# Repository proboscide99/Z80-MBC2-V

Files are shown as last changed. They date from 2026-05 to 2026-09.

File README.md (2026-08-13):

# Z80-MBC2-V

The **Z80-MBC2-V** is a variant of the popular Z80-MBC2 (Multi Boot Computer) by Just4Fun.

## Main Features
- WizNet W5500 ethernet port with TELNET capability (remote terminal - CP/M 3.0 physical device - CBBS)
- 512KB Supercap-backed RAM (some of which can be (has been) used for a CP/M 3.0 352KB RamDisk)
- RC2014 bus and Test points for I/O expansion / logic analysis
- Optional 8-24V power supply
- USB-C port for power and serial communication
- TTL serial I/O (as an alternative to USB)
- 3,3V I2C interface for a small (128x64) auxiliary onboard OLED display
- Z80 CMOS running up to 10MHz
- ATMega1284P for I/O
- RTC
- Hardware watchdog for ATmega and IOS-based software watchdog for Z80
- Fully software compatible with original project

## 🌐 Project Page
[https://www.probosci.de/Z80mbc](https://www.probosci.de/Z80mbc)

---

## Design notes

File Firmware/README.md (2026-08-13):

## AVR 1284P MCU Programming

This project has been tested using **Arduino IDE 1.8.19** with **MightyCore v2.2.2**, so the verified instructions provided below are related to this environment.

You can, of course, compile it from source and program it into the MCU using Arduino IDE 2.x and a more recent version of MightyCore.  

If you use a different tool version, please leave a message so the instructions for that specific setup can be added.

If your device is blank, you first need to program it using an external hardware programmer (you cannot upload the sketch directly via the serial port).

The repository provides both source code and pre-compiled .hex files (with and without a bootloader).  
The bootloader embedded in the file is **Optiboot**, configured for a **20MHz** crystal.

---

## Why MightyCore 2.2.2?

* Older versions lack functionalities required for this project (such as the ability to configure the serial buffer size)  
* Newer versions (starting from v3.x) replaced the Optiboot bootloader with Urboot, which is not compatible with IDE 1.8.19  

> [!NOTE]
> MightyCore v2.2.2 can be easily found online. A copy of the archive is also included in this repository.

Two files from the original 2.2.2 MightyCore need to be modified: `avrdude.conf` (mandatory) and `boards.txt` (recommended).

### 1. avrdude.conf
Even though MightyCore 2.2.2 is the correct core to use for IDE 1.8.19, its bundled `avrdude.conf` file was already prepared for the transition to AVRDUDE 7.x.  
It contains directives—such as `default_spi = "";`—that the AVRDUDE 6.3 interpreter cannot understand.

Replace this file with the native one from your Arduino IDE installation:
* **Source File**: `arduino-1.8.19/hardware/tools/avr/etc/avrdude.conf`
* **Destination Path**: `hardware/MightyCore/avr/avrdude.conf`

After this change, MightyCore 2.2.2 will work flawlessly with Arduino v1.8.19.

### 2. boards.txt
A modified `boards.txt` file is included in this repository with two simple, minor changes in the `1284/P` section.
If you have already customized your `boards.txt` file, do not replace it; just modify these two lines instead:

In the `1284/P` section:

* **Change the lock bits value** from `0xcf` to `0x0f` (using the older `0xCF` value would cause a non-fatal validation error):
  ```text
  #1284.bootloader.lock_bits=0xcf
  1284.bootloader.lock_bits=0x0f
  ```

* **Locate the row** `1284.menu.LTO.Os.compiler.cpp.extra_flags=` and add `-DSERIAL_RX_BUFFER_SIZE=1024`, so the line looks like:
  ```text
  1284.menu.LTO.Os.compiler.cpp.extra_flags=-DSERIAL_RX_BUFFER_SIZE=1024
  ```

This configures a larger (1KB) serial buffer size, allowing the Z80-MBC2 IOS firmware to better handle data transfers over the serial port.
IOS will recognize this flag and display the buffer size in the boot menu.

---

## Programming the MCU

For testing purposes, you may do this with a minimal hardware configuration (i.e., without the Z80, RAM, SD-CARD, Ethernet, and surrounding logic installed).  

If the board is fully populated, there is no need to unplug any component prior to programming the MCU.

In this example, an home-made `stk500v1` programmer has been used (see the picture below).

Connect your programmer to the 6-pin **J3** connector located on the right of the USB module, above the **Reset** button.  
This is the standard SPI programming connector found on almost any Arduino board.  

A small circle indicates the position of **Pin 1**, which is in the lower-left corner (brown wire in the picture).  

You probably won't need to apply power to the board, as many hardware programmers supply 5V directly to the target MCU.  

<br>
<p align="center">
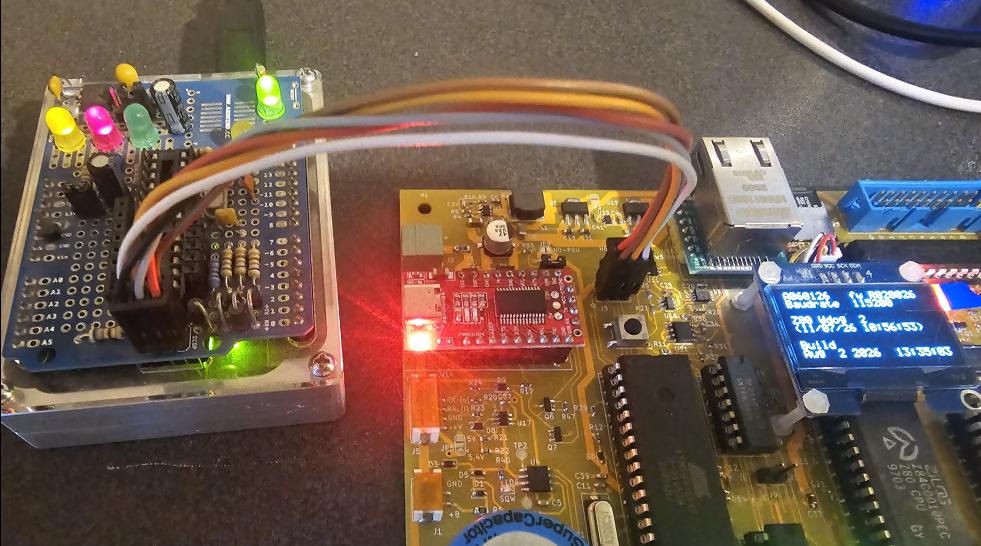
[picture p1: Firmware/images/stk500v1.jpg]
Connecting an stk500v1 programmer
  <br>
  <em>Connecting an stk500v1 programmer</em>
</p>
<br>

### Option A: Programming using the Arduino IDE

The only library required to compile and program this project is MightyCore (v2.2.2 for legacy Arduino 1.8.19 IDE).

1. Start the IDE and open the `IOS-MBC2V` project
2. Set the IDE according to the picture below (this screenshot shows the MightyCore v2.2.2 settings)  

<br>
<p align="center">
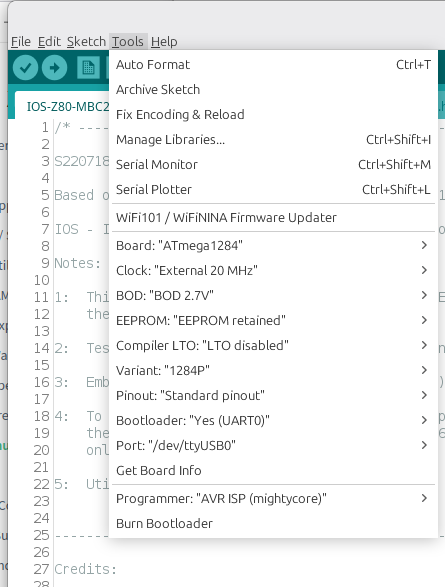
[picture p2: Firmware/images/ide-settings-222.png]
IDE 1.8.19 Settings for MightyCore v2.2.2
  <br>
  <em>IDE 1.8.19 Settings for MightyCore v2.2.2</em>
</p>
<br>

3. **If you want to be (later) able to upload via USB-C serial port**: Select **Burn Bootloader** from the *Tools* menu.  
After this step, the external programmer is no longer needed.  
When a bootloader is flashed, the **IOS** LED blinks to signal readiness for serial firmware upload.  
Connect a USB-C cable to the serial adapter on the board, select the proper port in the IDE, and click **Upload**  

4. **If you want to flash directly via hardware programmer**: Hold the `SHIFT` key down while clicking the **Upload** icon.  
You will need the programmer every time you upgrade the IOS firmware

### Option B: Programming from Command-Line

These examples show how to flash the pre-compiled .hex files using an `stk500v1` programmer on port `/dev/ttyACM0` at `115200` baud under Linux with AVRDUDE 6.x.  
Modify the options to suit your specific hardware setup.

First, open a command-line console and navigate to the directory above your Arduino installation.  
Copy the target .hex file into this working folder to avoid typing long paths.

#### Command for version WITHOUT the bootloader:
```sh
arduino-1.8.19/hardware/tools/avr/bin/avrdude -Carduino-1.8.19/hardware/MightyCore/avr/avrdude.conf -v -patmega1284p -cstk500v1 -P/dev/ttyACM0 -b115200 -e -Ulfuse:w:0xF7:m -Uhfuse:w:0xD7:m -Uefuse:w:0xFD:m -Ulock:w:0x3F:m -Uflash:w:IOS-Z80-MBC2-V.ino_atmega1284p_20000000L.hex:i
```

#### Command for version WITH the bootloader:
```sh
arduino-1.8.19/hardware/tools/avr/bin/avrdude -Carduino-1.8.19/hardware/MightyCore/avr/avrdude.conf -v -patmega1284p -cstk500v1 -P/dev/ttyACM0 -b115200 -e -Ulfuse:w:0xF7:m -Uhfuse:w:0xD6:m -Uefuse:w:0xFD:m -Ulock:w:0x3F:m -Uflash:w:IOS-Z80-MBC2-V.ino.with_bootloader_atmega1284p_20000000L.hex:i -Ulock:w:0x0F:m
```

---

## Pre-compiled Binaries Reference

| Filename | Description |
| :--- | :--- |
| **IOS-Z80-MBC2-V.ino_atmega1284p_20000000L.hex** | Pre-compiled firmware (20Mhz xtal) |
| **IOS-Z80-MBC2-V.ino.with_bootloader_atmega1284p_20000000L.hex** | Pre-compiled firmware with Optiboot Bootloader (20Mhz xtal) |

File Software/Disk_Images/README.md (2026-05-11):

Z80-MBC2-V is fully compatible with original project's disk images.  
You can prepare your sd-card using the original archive, then you may replace some files when you want to unlock specific features.  

| File | Description |
| :--- | :--- |
| **SD-S220718-R290823-v2** | Original Z80-MBC2 disk images |
| **DS2N00.DSK** | Replacement for CP/M 3.0 drive A: with custom BIOS (Telnet device, ramdisk) |
| **CPMLDR.COM** | Replacement for CP/M 3.0 loader (updates the release date printed at boot) |
| **DS2N07.DSK** | Replacement for CP/M 3.0 drive H: (custom BIOS development disk) |

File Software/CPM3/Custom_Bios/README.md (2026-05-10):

This modified CP/M 3.0 BIOS features an Ethernet **TELNET I/O device** and a **RAMDisk**.

It is based on the work of agn453 (agn453/Z80-MBC2-master) on the Z80-MBC2 CP/M 3.0 BIOS.

The main changes are in files CHARIO.MAC (telnet device) and VDISK.MAC (Ram Disk).

Ready-to-use disk images are available in the Software/Disk_Images section.  

The ZPM3 version of the BIOS still provides the 61KB TPA achieved by agn453.

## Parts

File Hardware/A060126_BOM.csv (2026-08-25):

Reference | Qty | Value | Footprint | Source
C1,C5,C14,C15,C16,C17,C19,C21,C22,C23,C24,C25,C26,C27,C28,C32,C34,C36,C38,C39,C40,C41,C42,C43 | 24 | 220nF 50V | 0603_1608Metric
C2 | 1 | 47uF 35V | 6.3x5.9
C3 | 1 | 10uF 35V | 1206_3216Metric
C4 | 1 | FG0H475ZF | Supercapacitor FG0H475ZF | https://www.mouser.it/ProductDetail/KEMET/FG0H475ZF?qs=98WN%2FnWUQiQ21tWcPMcRpQ%3D%3D
C6,C9,C12,C35 | 4 | 100nF 50V | 0603_1608Metric
C7,C8 | 2 | 22uF 10V | 1206_3216Metric
C10,C11 | 2 | 22pF | 0603_1608Metric
C13,C29,C30,C31,C37 | 5 | 10uF 10V | 0805_2012Metric
C18 | 1 | 10pF 50V | 0603_1608Metric
C20 | 1 | 47pF 50V | 0603_1608Metric
C33 | 1 | 1uF 10V | 0603_1608Metric
D1,D5,D6,D10 | 4 | 1PS76SB70_115 | SOD-323F | https://www.mouser.it/ProductDetail/Nexperia/1PS76SB70115?qs=P62ublwmbi%252BV7zpLU0e%252BsA%3D%3D
D2 | 1 | PMEG6030EVP | SOD-128 | https://www.mouser.it/ProductDetail/Nexperia/PMEG6030EVP-QX?qs=e8oIoAS2J1Rz8Ztu31J6Bg%3D%3D
D3,D8,D9 | 3 | SD05_SOD323 | SOD-323F | https://www.mouser.it/ProductDetail/Littelfuse/SD05-01FTG?qs=KLh5H0KA3COy3%252Bmz8p7W%252Bg%3D%3D
D4 | 1 | SMAJ24A | SMA | https://www.mouser.it/ProductDetail/Vishay-Semiconductors/SMAJ24A?qs=N78E2i60HJ5M5XdBeXM0ag%3D%3D
D7 | 1 | 1N4148 | LL4148 MiniMELF | https://www.mouser.it/ProductDetail/Diotec-Semiconductor/LL4148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
F1 | 1 | 2A | 1206_3216Metric | https://www.mouser.it/ProductDetail/Vishay-Sfernice/S2F120663V2A00TT?qs=4dK74SdgGtxaMukbYzVi2A%3D%3D
J1 | 1 | B2B-PH-SM4-TB | JST_B2B-PH-SM4-TB | https://www.mouser.it/ProductDetail/JST-Commercial/B2B-PH-SM4-TBLFSN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
J2 | 1 | MC_1,5_2-G-3.81 | PhoenixContact_MC_1,5_2-G-3.81_1x02_P3.81mm_Horizontal | https://www.digikey.it/it/products/detail/molex/0395126002/2736022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
J3 | 1 | ICSP | PinHeader_2.54mm:PinHeader_2x03_P2.54mm_Vertical
J4 | 1 | RC2014 | PinHeader_2.54mm:PinHeader_1x40_P2.54mm_Vertical
J5 | 1 | B4B-PH-SM4-TB | JST_B4B-PH-SM4-TB | https://www.digikey.it/it/products/detail/jst-sales-america-inc/B4B-PH-SM4-TB/926643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
J6 | 1 | Micro_SD_Card_Det_Hirose_DM3D-SF | microSD_HC_Hirose_DM3D-SF | https://www.digikey.it/it/products/detail/hirose-electric-co-ltd/DM3D-SF/1786510
J7 | 1 | BM04B-SRSS-TB_LF__SN_ | JST_BM04B-SRSS-TB_LF__SN_ | https://www.digikey.it/it/products/detail/jst-sales-america-inc/BM04B-SRSS-TB/926696
J8 | 1 | GPIO | IDC-Header_2x10_P2.54mm_Vertical
J9,J10,J12,J13,J14 | 5 | Conn_01x02_Pin | PinHeader_2.54mm:PinHeader_1x02_P2.54mm_Vertical
J11 | 1 | Conn_01x03_Pin | PinHeader_2.54mm:PinHeader_1x03_P2.54mm_Vertical
JP2 | 1 | ICSP | TestPoint:TestPoint_2Pads_Pitch2.54mm_Drill0.8mm
L1 | 1 | 10uH LQS_8040 | Inductor WE-LQS_8040 | https://www.digikey.it/it/products/detail/w%C3%BCrth-elektronik/74404084100/4865710
 |  |  |  | https://it.rs-online.com/web/p/induttori-smd/8164720P
LD1 | 1 | LED_B | LED_PLCC-2_3.4x3.0mm_KA
LD2 | 1 | LED_G | LED_PLCC-2_3.4x3.0mm_KA
LD3,LD4 | 2 | LED_Y | LED_PLCC-2_3.4x3.0mm_KA
LD5 | 1 | LED_R | LED_PLCC-2_3.4x3.0mm_KA
LD6,LD8,LD13 | 3 | LED G | LED_SMD:LED_0603_1608Metric
LD7 | 1 | LED B | LED_SMD:LED_0603_1608Metric
LD9,LD12 | 2 | LED Y | LED_SMD:LED_0603_1608Metric
LD10,LD11,LD15 | 3 | LED R | LED_SMD:LED_0603_1608Metric
LD14 | 1 | LED W | LED_SMD:LED_0603_1608Metric
Q1,Q2,Q10 | 3 | BC807 | SOT-23
Q3,Q4,Q5,Q6,Q7 | 5 | BSS138 | SOT-23
Q8 | 1 | FDN340P | SOT-23 | https://www.mouser.it/ProductDetail/onsemi/FDN340P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
Q9 | 1 | BC847 | SOT-23
R1 | 1 | 100R | 0805_2012Metric
R2,R3,R6,R7,R8,R18,R19,R20,R21,R48,R54 | 11 | 1K | 0603_1608Metric
R4 | 1 | 150K | 0603_1608Metric
R5 | 1 | 27K | 0603_1608Metric
R9 | 1 | 17K4 | 0603_1608Metric
R10,R56,R59 | 3 | 100K | 0603_1608Metric
R11,R53 | 2 | 330R | 0603_1608Metric
R12,R26,R27,R30,R34,R39,R40,R41,R43,R49,R55,R58 | 12 | 10K | 0603_1608Metric
R13,R14 | 2 | 390R | 0603_1608Metric
R15 | 1 | 39R | 0603_1608Metric
R16,R17,R25,R29,R31,R32,R36,R37,R44,R45,R46,R47,R50 | 13 | 4K7 | 0603_1608Metric
R22 | 1 | 15K | 0603_1608Metric
R23,R24 | 2 | 470R | 0603_1608Metric
R28 | 1 | 100R | 0603_1608Metric
R33,R35,R38,R57,R60 | 5 | 2K2 | 0603_1608Metric
R42 | 1 | 3K6 | 0603_1608Metric
R51 | 1 | 47K | 0603_1608Metric
R52 | 1 | 22K | 0603_1608Metric
RN1,RN2 | 2 | 10K | R_Array_SIP9
RN3 | 1 | 10K | R_Array_SIP5
SW1,SW2,SW3 | 3 | SW_Omron_B3FS | SW_SPST_Omron_B3FS-1010P | https://www.digikey.it/it/products/detail/omron-electronics-inc-emc-div/B3FS-1010/1811743
U1 | 1 | 74HC02 | DIP-14_W7.62mm | https://www.mouser.it/ProductDetail/Texas-Instruments/SN74HC02NE4?qs=mE33ZKBHyE6%252BoPtm0GsdUg%3D%3D
U2 | 1 | MAX693AESE | SOIC-16_3.9x9.9mm_P1.27mm | https://www.digikey.it/en/products/detail/analog-devices-inc-maxim-integrated/MAX693AESE/1512245
U3 | 1 | AP63201WU | TSOT-23-6 | https://www.mouser.it/ProductDetail/Diodes-Incorporated/AP63201WU-7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
U4 | 1 | DS3231MZ | SOIC-8_3.9x4.9mm_P1.27mm | https://www.digikey.it/it/products/detail/analog-devices-inc-maxim-integrated/DS3231MZ-TRL/2754408
U5 | 1 | ADP3338AKCZ-5 | SOT-223 | https://www.digikey.it/en/products/detail/analog-devices-inc/ADP3338AKCZ-5-REEL/994041
U6 | 1 | ATmega1284P-P | DIP-40_W15.24mm | https://www.digikey.it/it/products/detail/microchip-technology/ATMEGA1284P-PU/1914521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
U7 | 1 | 74HC32 | DIP-14_W7.62mm | https://www.mouser.it/ProductDetail/Texas-Instruments/SN74HC32NE4?qs=AgY10sKTvDKvoRvnDPHQkQ%3D%3D
U8 | 1 | 74HC75 | DIP-16_W7.62mm | https://www.mouser.it/ProductDetail/Texas-Instruments/CD74HC75E
U9 | 1 | 74HC08 | DIP-14_W7.62mm | https://www.mouser.it/ProductDetail/Texas-Instruments/SN74HC08AN?qs=byeeYqUIh0O9MyGywGYg%252Bw%3D%3D
U10 | 1 | Z84C00xxP | DIP-40_W15.24mm | Ebay
U11,U16,U24 | 3 | 74LVC2G17DBV | SOT-23-6 | https://www.mouser.it/ProductDetail/Texas-Instruments/SN74LVC2G17DBVR?qs=X1HXWTtiZ0RnstCufGEJxQ%3D%3D
U12,U22 | 2 | 74LV1T32GV | SOT-23-5 | https://www.mouser.it/ProductDetail/Nexperia/74LV1T32GVH?qs=Cb2nCFKsA8qBSWWC7FqyYg%3D%3D
U13 | 1 | AS6C4008-55PCN | DIP-32_W15.24mm | https://www.mouser.it/ProductDetail/Alliance-Memory/AS6C4008-55PCN?qs=E5c5%252Bmu3i3%252BMOyro1Tlhzg%3D%3D
U14 | 1 | FT232_M | FT232_MODULE | Aliexpress
U15 | 1 | W5500-MINI | W5500-MINI | Aliexpress
U17 | 1 | 74HCT2G17DBV | SOT-23-6 | https://www.digikey.it/it/products/detail/nexperia-usa-inc/74HCT2G17GV-125/1300827
U18 | 1 | 74AHCT2G125DP | TSSOP-8_3x3mm_P0.65mm | https://www.digikey.it/en/products/detail/nexperia-usa-inc/74AHCT2G125DP-125/1229696
 |  |  |  | https://eu.mouser.com/ProductDetail/Nexperia/74AHCT2G125DP125?qs=P62ublwmbi%2FS7fXZumeLoQ%3D%3D
U19 | 1 | ADP3338AKCZ-3.3 | SOT-223 | https://www.digikey.it/it/products/detail/analog-devices-inc/ADP3338AKCZ-3-3RL7/820221
U20 | 1 | MCP23017_SP | DIP-28_W7.62mm | https://www.digikey.it/en/products/detail/microchip-technology/MCP23017-E-SP/894272
U21 | 1 | FM24C64B-G | SOIC-8_3.9x4.9mm_P1.27mm | https://www.mouser.it/en/ProductDetail/Infineon-Technologies/FM24C64B-G?qs=pA5MXup5wxGwtHrVZCxLVQ%3D%3D
U23 | 1 | LM66100DCK | SOT-363_SC-70-6 | https://www.mouser.it/ProductDetail/Texas-Instruments/LM66100DCKR
Y1 | 1 | 20MHz XTAL | HC49-SD | https://www.mouser.it/ProductDetail/ABRACON/ABLS-20000MHZ-B2-T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
 | 1 | OLED Display |  | https://www.amazon.it/dp/B0DFCKSWH9?sp_csd=d2lkZ2V0TmFtZT1zcF9kZXRhaWw
 | 3 | 14PIN_DIL_socket | DIP-14_W7.62mm_Socket
 | 1 | 16PIN_DIL_socket | DIP-16_W7.62mm_Socket
 | 1 | 28PIN_DIL_socket | DIP-28_W7.62mm_Socket | https://www.mouser.it/ProductDetail/Preci-dip/110-83-328-41-001101?qs=uQD7XCvsSCMckus%252ByY0uUg%3D%3D
 | 2 | 40PIN_DIL_socket | DIP-40_W15.24mm_Socket

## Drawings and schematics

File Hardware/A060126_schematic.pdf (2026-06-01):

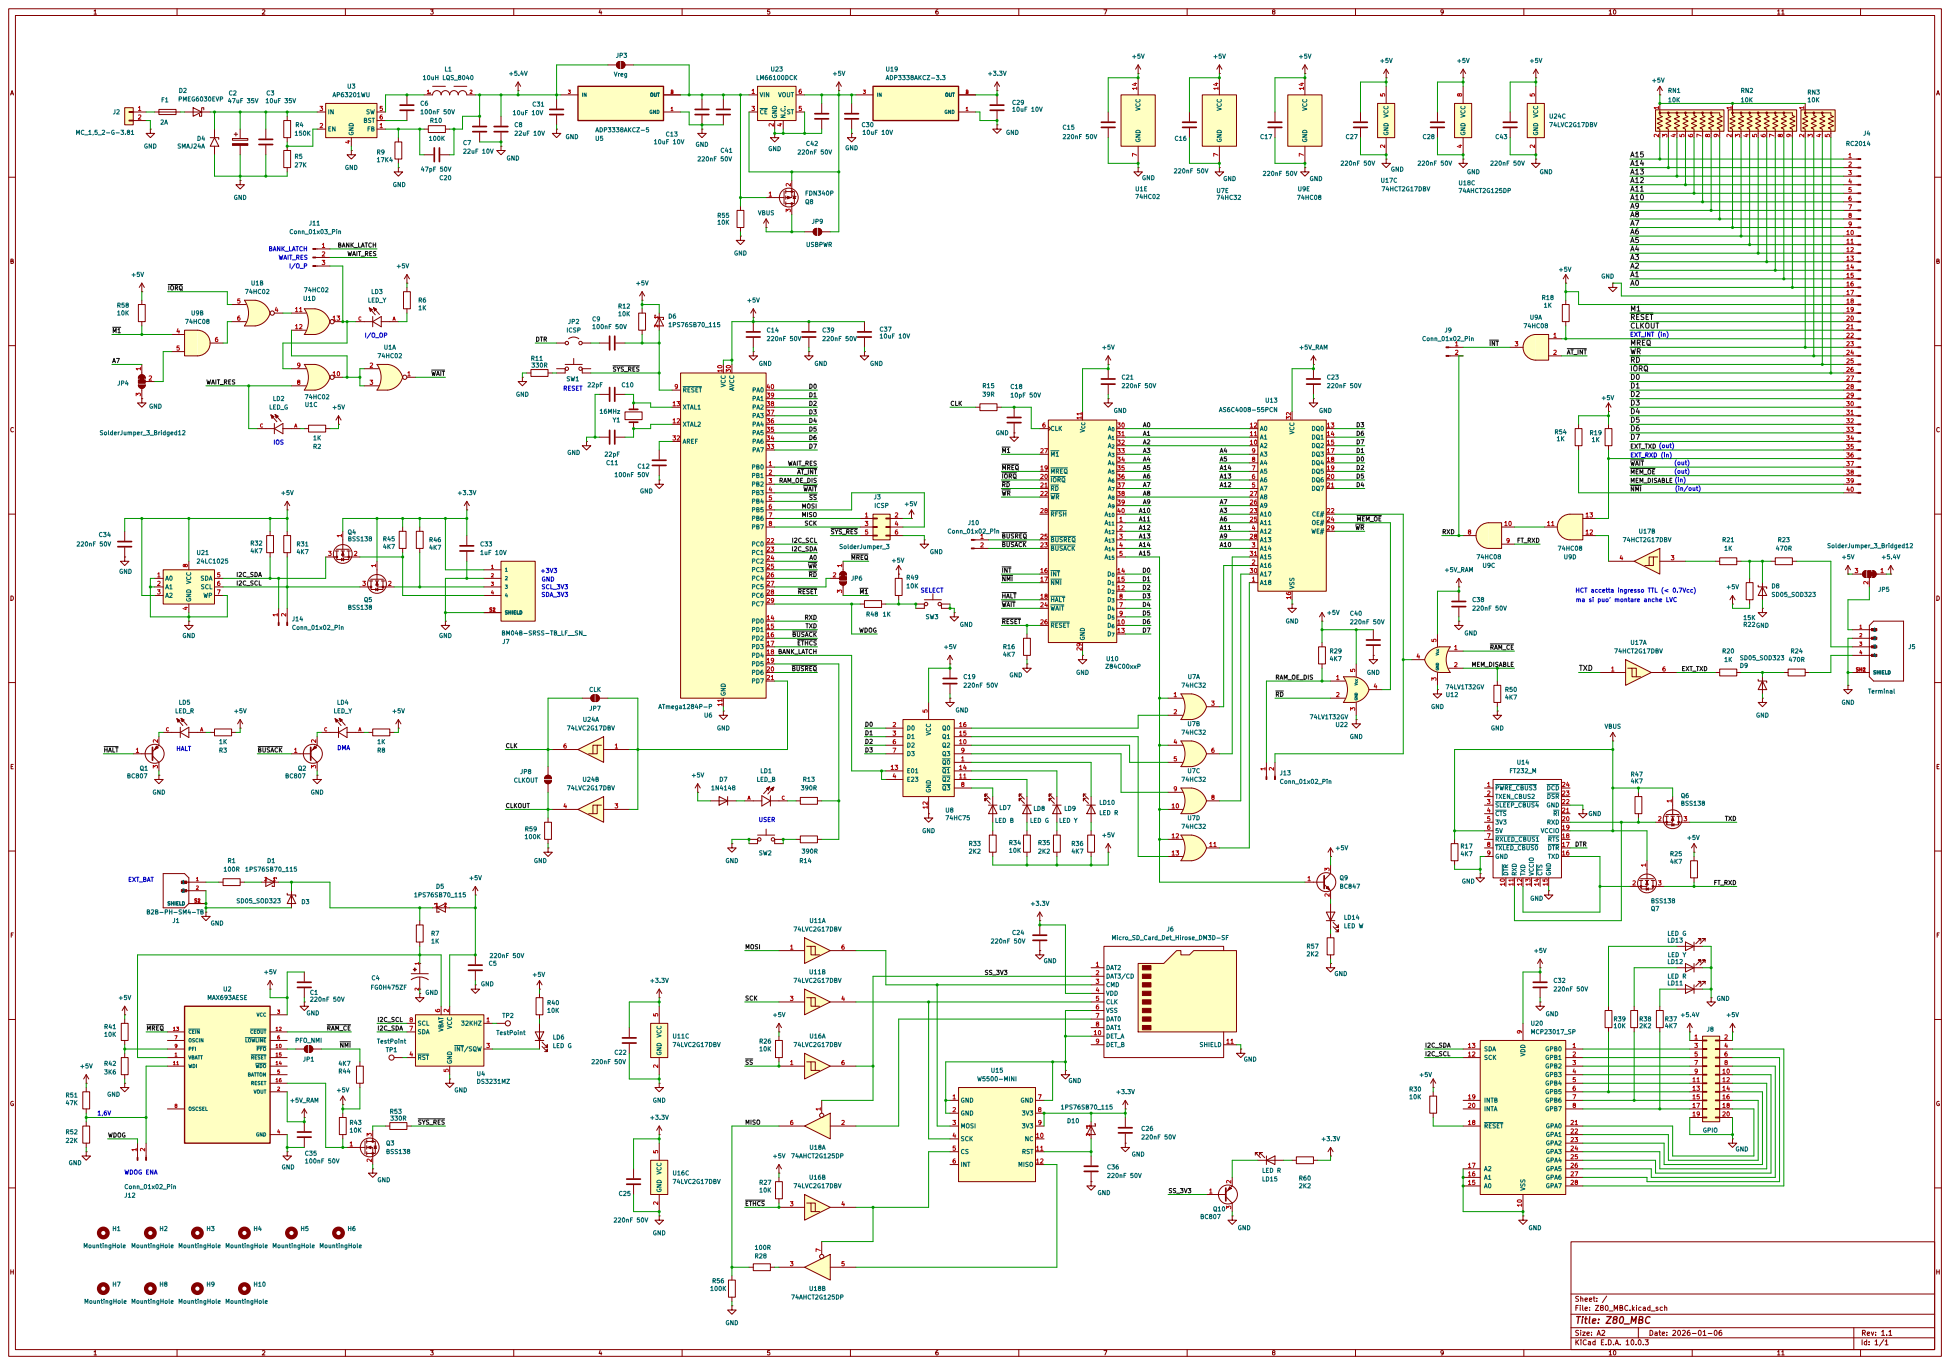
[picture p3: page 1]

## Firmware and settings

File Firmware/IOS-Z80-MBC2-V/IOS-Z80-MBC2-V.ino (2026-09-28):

/* ------------------------------------------------------------------------------

S220718-R280926 - HW ref: A060126

Based on original Z80-MBC2 project version S220718-R290823 IOS

IOS - I/O Subsystem for the  Z80-MBC2-V (Multi Boot Computer - Z80 512kB RAM @ 5/10Mhz @ Fosc = 20MHz)

Notes:

1:  This SW is for the Atmega1284P used as EEPROM and I/O subsystem (20MHz external oscillator) for the Z80 CPU.
    
2:  Tested on Atmega1284P @ Arduino IDE 1.8.19 and MightyCore v.2.2.2
    Settings:
    Board:          ATmega 1284
    Clock:          External 20MHz
    Bod:            Bod 2,7V
    EEPROM:         EEprom retained
    Compiler LTO:   LTO Disabled
    Variant:        1284P
    Pinout:         Standard Pinout
    Bootloader:     Yes (UART0)


3:  Embedded FW: S200718 iLoad (Intel-Hex loader)

4:  To run the stand-alone Basic and Forth interpreters the SD optional module must be installed with 
    the required binary files on a microSD (FAT16 or FAT32 formatted). Without the SD module you can 
    only run the iLoad loader.

5:  Utilities:   S111216 TASM conversion utility


---------------------------------------------------------------------------------

Credits:

SD library from: https://github.com/greiman/PetitFS (based on 
PetitFS: http://elm-chan.org/fsw/ff/00index_p.html)

PetitFS licence:
/-----------------------------------------------------------------------------/
/  Petit FatFs - FAT file system module  R0.03                  (C)ChaN, 2014
/-----------------------------------------------------------------------------/
/ Petit FatFs module is a generic FAT file system module for small embedded
/ systems. This is a free software that opened for education, research and
/ commercial developments under license policy of following trems.
/
/  Copyright (C) 2014, ChaN, all right reserved.
/
/ * The Petit FatFs module is a free software and there is NO WARRANTY.
/ * No restriction on use. You can use, modify and redistribute it for
/   personal, non-profit or commercial products UNDER YOUR RESPONSIBILITY.
/ * Redistributions of source code must retain the above copyright notice.
/
/-----------------------------------------------------------------------------/

Credits:

Thanks to Christian Welzel (http://www.welzel-online.ch) for some suggestions 
on Fuzix IRQ handling.

---------------------------------------------------------------------------------


CHANGELOG:

S071225-R071225   MCU_RTS_  renamed to SEL_WDOG ('SELECT' button input / hardware watchdog control)
                  MCU_CTS_  renamed to BUSACK (connected to processor's BUSACK signal)
                  BANK1     renamed to ETH_CS (ethernet SPI chip select)
                  BANK0     renamed to BANK_LATCH (single signal for 4-bit latch, 512KB ram, 16 banks)
                  RAM_CE2   renamed to RAM_OE_DIS (ram output disable, active high)
                  WAIT_RES_ renamed to WAIT_RES (active high instead of active low)
                  Opcode 0x0D handler (write bank) modified to use the new 16-banks latch from Z80 databus
                  Inverted the polarity of WAIT_RES, now active high
                  'loadByteToRAM() and 'loadHL()' modified to use RAM_OE_DIS instead of RAM_CE2
                   (inverted logic, can be left active as does not interfere with write cycles)

S071225-R131225   Added flag 'irqPending' (INT postpone)
                  Added 'currentBank' that contains the number of currently selected bank
                  Added 'irqSafeBank' writable by Z80 to specify the bank which is safe for INT
                  Interrupts are issued only if current bank is safe and a BANK SELECT ('ioOpcode') is not in progress
                  Added ethernet test (web server at 192.168.0.176 when main loop is running)

S071225-R211225   Added RTC SQW enable command (blinking led)
                  Added 'WRDISPCTRL' and 'WRDISPDATA' write opcodes (OLED display)

S071225-R241225   Display library removed, OLED now controlled by bare metal routines, optimized to reduce blocking time.
                  10ms system tick based on TIMER1 used for SEL_WDOG drive (watchdog test) and Z80 interrupt tick,
                   which is now selectable in 10ms increments instead of 1.

S071225-R251225   Ethernet library removed, implemented a bare metal telnet server that operates like the serial terminal.
                  Both interfaces are working simultaneously: what is typed on one, is also visible on the other.
                  TODO: atmega Serial.print / get char is still on serial interface only.

S071225-R261225   Completed telnet handling, which now works at any level through menu and Z80 applications.
                  Added option to set the power-on default RAM bank.
                   This allows program such as "1: Basic", who allows Warm Start, to run in a dedicated bank. Data (basic listing)
                   is retained due to the battery backup.
                  Added option to enable/disable the boot of previous menu selection.

S071225-R271225   Text to telnet client is now always through a TX FIFO.
                   This allows a client to receive all the menu text and selections that were made before connecting.
                   Hence, the variable banner is no longer necessary and has been removed.
                  Corrected a problem introduced with default bank selection: CP/M and Fuzix require BANK0 as initial bank:
                   they start loading without setting it.
                  When the option is a S.O., bank is forced to zero.
                  Solved a bug that prevented 'UCSD Pascal' from receiving keystrokes from telnet: the availability of characters
                   should (also) be notified through the bitmap returned by 'SYSFLAGS' command, which is used by the program
                   to determine when to poll for characters.

S071225-R281225   Z80 Clock selectable between 2MHz - 8MHz (@16MHz) for testing purposes.

S071225-R291225   Z80 INT not asserted (postponed) not only if a 0x0D opcode is in progress (SETBANK), but if ANY opcode is in progress.
                   This prevents a poorly written Z80 firmware from being interrupted during I/O OP, truncating an ongoing sequence.
                  Corrected a bug that left ioOpcode = 0x84 (datetime) unless the host popped an additional byte (clear ioOpcode on the byte beyond the last).
                  Temporarily reduced MAX_RAM_BANK to 2.
                  Temporarily set DEBUG to 2.
                  Many debug messages added.

S071225-R301225   Restored DEBUG = 1 and MAX_BANK = 15.
                  SD speed restored to 8MHz.
                  For fuzix, 'Z80IntSysTick' is now set to 0 by default: it turned out to be the reason for random kernel panic.
                  Some fuzix functions require the systick interrupt (i.e. che fscheck to finalize the sd write). In this case, please use the '[pwd]I'
                   telnet special command to temporarily enable tick INT just after fir final reboot message, then wait for leds to stop blinking.

S071225-R311225   Network parameters now stored in internal EEprom.
                  Network settings configuration menu.
                  The 'telnet_handler()' is now called on a 10ms basis or immediately (loop freerun) when more that a certain amount of characters
                   are waiting to be transmitted to a connected client. This saves time and reduces SPI overhead.
                  The display is turned off when a menu' selection is made.
                  The main menu' is displayed again after changing any option.
                  Other minor changes.

S071225-R010126   GPIO / I/O cycle optimization: direct register read/write and BUSACK signal from Z80 allows quite a better performance in timings.

S071225-R020126   Fixed a bug in the set baudrate function.
                  New telnet RAW mode: allows xmodem transfers.
                  Two new opcodes has heen created to set/get 'telnet_flags' register to enable/disable features; by now, olny bit 0 is in use
                   (1 = RAW mode enabled).
                  When RAW mode is enabled, special commands and any other character handling is disabled to allow raw binary data flow.
                  New telnet special command [pwd]R that completely restarts the board (atmega soft reset).

S071225-R030126   New 'GETBANK' opcode that returns the number of the currently active ram bank, very useful for setting the ISR-safe bank.
                  Telnet RAW mode is automatically disabled when a client disconnects.
                   This allows special commands to work (they can't be processed while in RAW mode).
                  If something bad happens between the telnet server and client, W5500 may start receiving many (nearly infinite) character,
                   preventing the RX LOOP from exiting and stalling the Z80 in WAIT at the first I/O attempt (because the FF doesn't get serviced).
                   The RX loop has now a "max-byte-per-iteration" counter and also exits immediately if the software RX FIFO is full (because Z80 is stalled).
                   Sooner or later, the RX flow will terminate.
                  WAIT poll before asserting INT has been commented out. INT can be asserted during an I/O operation and will be served upon completion
                   (original behavior).

S071225-R040125   New #defines 'NO_INT_ON_ANY_OPCODE' and 'POLL_WAIT_BEFORE_INT' to control the way INT is asserted. See comments in the INT assertion section.

S071225-R090125   Bugfix in telnet 'NORMALIZATION RULES' that prevents the W5500 RX buffer from being read ahead of received bytes.
                  Value of 'SERIAL_RX_BUFFER_SIZE' now printed.

S071225-R100126   New 'sh1106_contrast()' function to set the display brightness.
                  The display is now turned off after about 1 minute even if the system is in the main menu.
                  The display is dimmed after 25 seconds of inactivity.

S071225-R110126   RX serial buffer size increased to 2K (1284.menu.LTO.Os.compiler.cpp.extra_flags=-DSERIAL_RX_BUFFER_SIZE=2048)
                  'DEBUG' level set to zero.

S071225-R130126   Changed default MAC address.
                  Security key 'yes' needed to confirm Network Config changes.

S071225-R310126   The SETTELNETFLAGS opcode is now a two-bytes command. The first byte is the SET mask and the second byte is the RESET mask.
                   This allows set/reset of a single bit without having to read previous state of the 'telnet_flags' register.
                  Support for new 'TELNET' device in CP/M 3.0 bios:
                   Telnet I/O is no longer bridged (copied) by default to IOS serial I/O.
                   Previous bridged mode is now enabled when new 'TFLAG_CON_BRIDGE' bit in 'telnet_flags' is SET (default '0', not enabled).
                   This bit can be (also) toggled by new telnet special command "[pwd]B", which allows gaining remote control of device.
                   Before this step, a telnet client does not transfer any byte to IOS nor Z80 serial I/O, but only through the 'TELNET' dedicated opcodes.
                  Three new opcodes defined:
                   0x44 TELNET TX: works as 'SERIAL TX' but sends a byte over telnet only;
                   0xC3 TELNET RX: works as 'SERIAL RX' but returns telnet received bytes only (unlike SERIAL RX, requires an opcode write for each character);
                   0xC2 GET TELNET STATUS, where d0 is 'available received bytes' flag and d1 is 'client is connected' flag.
                   These opcodes are used by the new 'TELNET' device defined in 'CHARIO.MAC' bios source of CP/M 3.0.

S071225-R030226   Two telnet socket now listening on different ports.
                  The SOCKET0 is still binded to the serial console when the 'TFLAG_CON_BRIDGE' bit is SET.
                  Telnet opcodes modified as follows:
                   0xC2 GETTELNETSTAT03  now returns pairs of "client connected"/"data available" bits for (up to) four sockets
                   0xC3 TELNET RX S0     rx bytes opcode for SOCKET 0, can be used only when the 'TFLAG_CON_BRIDGE' gridging mode is NOT active
                   0xC4 TELNET RX S1     rx bytes for SOCKET 1
                   0x43 SELTELNETSOCKET  allows setting the socket number for subsequent flags/status read/write operations
                   0x44 SETTELNETFLAGS   sets telnet flag byte for the currently selected socket
                   0x45  TELNET TX S0    tx bytes opcode for SOCKET 0. Unlike the RX function, this works regardless of the state of 'TFLAG_CON_BRIDGE' flag.
                   0x46  TELNET TX S1    tx bytes opcode for SOCKET 1.

S071225-R070226   New 'telnet_flags' bit 'TFLAG_DISCONNECT' that forces a client disconnection on selected socket.
                  Fixed a bug that prevented DISCONNECT cleanup upon call to 'w5500_disconnect()' because the function was setting 'last_state' to 'SOCK_CLOSED'.

S071225-R100226   New opcodes 0x49 and 0x4A for OR - AND bitmap write on GPE PORTA and PORTB respectively
                  Telnet port are now 2300 + socket number (i.e. 2300 for socket 0, 2301 for socket 1, etc)

S071225-R140226   New 'telnet_flags' bit 'TFLAG_PURGETXONCONN' that purges the telnet TX FIFO upon new client connection

S071225-R160226   When the telnet flag 'TFLAG_PURGETXONCONN' is reset (by SETTELNETFLAGS) and the socket is not connected, the TX fifo gets purged one last time.
                  The telnet flag 'TFLAG_CON_BRIDGE' is now meaningful also for socket other than 0: traffic gets forwarded from socket 'x' to serial and socket 0 (but not vice-versa)
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
void loop() 
{
  if (!(WAIT_PORTIN & (1 << WAIT_PIN)))
  // I/O operaton requested
  {
    Z80watchdog_ioOper = true;

    if (!(WR_PORTIN & (1 << WR_PIN)))
    // I/O WRITE operation requested

    // ----------------------------------------
    // VIRTUAL I/O WRITE OPERATIONS ENGINE
    // ----------------------------------------

    {
      ioAddress = (AD0_PORTIN & (1 << AD0_PIN));  // this way ioAddress gets the bit weight of the pin, but does not matter
      ioData = PINA;                              // Read Z80 data bus D0-D7 (PA0-PA7)
      if (ioAddress)                              // Check the I/O address (only AD0 is checked!)
      // .........................................................................................................
      //
      // AD0 = 1 (I/O write address = 0x01). STORE Opcode.
      //
      // Store (write) an "I/O operation code" (Opcode) and reset the exchanged bytes counter.
      //
      // NOTE 1: An Opcode can be a write or read Opcode, if the I/O operation is read or write.
      // NOTE 2: the STORE Opcode operation must always precede an EXECUTE WRITE Opcode or EXECUTE READ Opcode 
      //         operation.
      // NOTE 3: For multi-byte read Opcode (as DATETIME) read sequentially all the data bytes without to send
      //         a STORE Opcode operation before each data byte after the first one.
      // .........................................................................................................
      //
      // Currently defined Opcodes for I/O write operations:
      //
      //   Opcode     Name            Exchanged bytes
      // -------------------------------------------------
      // Opcode 0x00  USER LED        1
      // Opcode 0x01  SERIAL TX       1
      // Opcode 0x03  GPIOA Write     1
      // Opcode 0x04  GPIOB Write     1
      // Opcode 0x05  IODIRA Write    1
      // Opcode 0x06  IODIRB Write    1
      // Opcode 0x07  GPPUA Write     1
      // Opcode 0x08  GPPUB Write     1
      // Opcode 0x09  SELDISK         1
      // Opcode 0x0A  SELTRACK        2
      // Opcode 0x0B  SELSECT         1  
      // Opcode 0x0C  WRITESECT       512
      // Opcode 0x0D  SETBANK         1
      // Opcode 0x0E  SETIRQ          1
      // Opcode 0x0F  SETTICK         1
      // Opcode 0x10  SETOPT          1
      // Opcode 0x11  SETSPP          1
      // Opcode 0x12  WRSPP           1
      //
      // Opcodes for MBC2-V - 0x40 offset
      //
      // Opcode 0x40  SETIRQBANK      1           // set the INT-safe ram bank, 0xFF = all
      // Opcode 0x41  WRDISPCTRL      n           // set display control data (coordinates, etc)
      // Opcode 0x42  WRDISPDATA      n           // write display data (text)
      // Opcode 0x43  SELTELNETSOCKET 1           // set the current telnet socket (session) number
      // Opcode 0x44  SETTELNETFLAGS  2           // set telnet flags byte (SET MASK, RESET MASK) for currently selected socket
      // Opcode 0x45  TELNET TX S0    1           // send a byte over telnet socket 0
      // Opcode 0x46  TELNET TX S1    1           // send a byte over telnet socket 1
      // Opcode 0x47  TELNET TX S2    1           // RESERVED for socket 2
      // Opcode 0x48  TELNET TX S3    1           // RESERVED for socket 3
      // Opcode 0x49  GPIOASETRESET   2           // Write to GPIO port A expander with OR / AND masks
      // Opcode 0x4A  GPIOBSETRESET   2           // Write to GPIO port B expander with OR / AND masks
      // Opcode 0x4B  SETWATCHDOG     2           // Set Z80 watchdog timeout and reset type (TRUE / INVERTED value)
      // Opcode 0x4C  SETFRAMPARAMS   3           // Set F-RAM address (16 bit) and datalen (8 bit) for next rd/wr operation
      // Opcode 0x4D  FRAMWRITE       n           // F-RAM data write
      //
      //
      //
      // Currently defined Opcodes for I/O read operations:
      //
      //   Opcode     Name            Exchanged bytes
      // -------------------------------------------------
      // Opcode 0x80  USER KEY        1
      // Opcode 0x81  GPIOA Read      1
      // Opcode 0x82  GPIOB Read      1
      // Opcode 0x83  SYSFLAGS        1
      // Opcode 0x84  DATETIME        7
      // Opcode 0x85  ERRDISK         1
      // Opcode 0x86  READSECT        512
      // Opcode 0x87  SDMOUNT         1
      // Opcode 0x88  ATXBUFF         1
      // Opcode 0x89  SYSIRQ          1
      // Opcode 0x8A  GETSPP          1
      //
      // Opcodes for MBC2-V - 0xC0 offset
      //
      // Opcode 0xC0  GETTELNETFLAGS  1           // get telnet flags for currently selected socket
      // Opcode 0xC1  GETBANK         1           // get the active bank number
      // Opcode 0xC2  GETTELNETSTAT03 1           // get telnet read only status bits for sockets 0...3
      // Opcode 0xC3  TELNET RX S0    1           // get a byte from telnet socket 0
      // Opcode 0xC4  TELNET RX S1    1           // get a byte from telnet socket 1
      // Opcode 0xC5  TELNET RX S2    1           // RESERVED for socket 2
      // Opcode 0xC6  TELNET RX S3    1           // RESERVED for socket 3
      // Opcode 0xC7  ETH REMOTE IP   5           // get the IP address and proxy state of the device connected to the selected socket (see SELTELNETSOCKET)
      // Opcode 0xC8  FRAMGETPARAMS   1           // get F-RAM transferred bytes
      // Opcode 0xC9  FRAMREAD        n           // F-RAM data read
      //
      // Opcode 0xFF  No operation    1
      //
      // See the following lines for the Opcodes details.
      // 
      // .........................................................................................................     
      {
#if DEBUG > 0
        if (ioOpcode != 0xFF)
          consolePrint("[PROTO] WR OPCODE (OUT1), 0x%02X while ioOpcode = 0x%02X, ioByteCnt = %u\r\n", ioData, ioOpcode, ioByteCnt);
#endif
#if DEBUG > 3
        if (ioOpcode != 0xFF)
          digitalWrite(SEL_WDOG, HIGH);           // opcode write trigger
#endif

        ioOpcode = ioData;                        // Store the I/O operation code (Opcode)
        ioByteCnt = 0;                            // Reset the exchanged bytes counter
      }
      else
      // .........................................................................................................
      //
      // AD0 = 0 (I/O write address = 0x00). EXECUTE WRITE Opcode.
      //
      // Execute the previously stored I/O write Opcode with the current data.
      // The code of the I/O write operation (Opcode) must be previously stored with a STORE Opcode operation.
      // .........................................................................................................
      //
      {
        switch (ioOpcode)
        // Execute the requested I/O WRITE Opcode. The 0xFF value is reserved as "No operation".
        {
          case  0x00:
            // USER LED:      
            //                I/O DATA:    D7 D6 D5 D4 D3 D2 D1 D0
            //                            ---------------------------------------------------------
            //                              x  x  x  x  x  x  x  0    USER Led off
            //                              x  x  x  x  x  x  x  1    USER Led on
            
            if (ioData & 0x01) digitalWrite(USER, LOW); 
            else digitalWrite(USER, HIGH);
          break;

          case  0x01:
            // SERIAL TX:     
            //                I/O DATA:    D7 D6 D5 D4 D3 D2 D1 D0
            //                            ---------------------------------------------------------
            //                             D7 D6 D5 D4 D3 D2 D1 D0    ASCII char to be sent to serial / telnet
            
            Serial.write(ioData);

            if (eth_ok && (telnet_sessions[0].telnet_flags & TFLAG_CON_BRIDGE))
              telnet_tx_push(0, ioData);
          break;

          case  0x03:
            // GPIOA Write (GPE Option):
            //
            //                I/O DATA:    D7 D6 D5 D4 D3 D2 D1 D0
            //                            ---------------------------------------------------------
            //                             D7 D6 D5 D4 D3 D2 D1 D0    GPIOA value (see MCP23017 datasheet)
            
            gpioPortA_M = ioData;
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

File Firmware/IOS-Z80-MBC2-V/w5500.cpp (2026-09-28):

#include <avr/io.h>
#include <Arduino.h>
#include "w5500.h"
#include <avr/wdt.h>

#define   DEBUG             1                             // Debug: 0 = Off, 1 = Light, 2+ = Exhaustive

// ---------------------------------------------------------
//  DEFINIZIONI HARDWARE
// ---------------------------------------------------------
#define ETH_SELECT()    (ETH_CS_PORT &= ~(1 << ETH_CS_PIN))
#define ETH_DESELECT()  (ETH_CS_PORT |=  (1 << ETH_CS_PIN))

// ---------------------------------------------------------
//  W5500 COMMON REGISTERS
// ---------------------------------------------------------
#define MR                  0x0000
#define GAR0                0x0001
#define SUBR0               0x0005
#define SHAR0               0x0009
#define SIPR0               0x000F
#define RTR0                0x0019                        // Retry Time-value Register (MSB)
#define RCR                 0x001B                        // Retry Count Register
// ---------------------------------------------------------
//  SOCKET REGISTERS
// ---------------------------------------------------------
#define Sn_MR               0x0000
#define Sn_CR               0x0001
#define Sn_SR               0x0003
#define Sn_PORT             0x0004
#define Sn_DIPR             0x000C

#define Sn_RXBUF_SIZE       0x001E
#define Sn_TXBUF_SIZE       0x001F

#define Sn_TX_FSR           0x0020
#define Sn_TX_RD            0x0022
#define Sn_TX_WR            0x0024

#define Sn_RX_RSR           0x0026
#define Sn_RX_RD            0x0028
#define Sn_RX_WR            0x002A

#define Sn_KPALVTR          0x002F

// ---------------------------------------------------------
//  BUFFER SIZE DEFS AND MASKS
//  2 SOCKET: MAX 8KB;
//  4 SOCKET: MAX 4KB;
//  8 SOCKET: MAX 2KB.
// ---------------------------------------------------------
#define S_TXBUF_MASK       0x0FFF                         // 4KB
#define S_RXBUF_MASK       0x0FFF                         // 4KB
#define BUF_SIZE_4K         0x04

// ---------------------------------------------------------
//  BLOCK SELECT PER SOCKET n
// ---------------------------------------------------------
//#define S_REG(sn)   (((uint8_t)(sn) << 2) + 1)
//#define S_TXB(sn)   (((uint8_t)(sn) << 2) + 2)
//#define S_RXB(sn)   (((uint8_t)(sn) << 2) + 3)

#define S_REG(sn)   ((((uint8_t)(sn) << 2) + 1) << 3)
#define S_TXB(sn)   ((((uint8_t)(sn) << 2) + 2) << 3)
#define S_RXB(sn)   ((((uint8_t)(sn) << 2) + 3) << 3)
/*
  00000 Selects Common Register.
  00001 Selects Socket 0 Register
  00010 Selects Socket 0 TX Buffer
  00011 Selects Socket 0 RX Buffer
  00100 Reserved
  00101 Selects Socket 1 Register
  00110 Selects Socket 1 TX Buffer
  00111 Selects Socket 1 RX Buffer
  01000 Reserved
  [...]
  11101 Selects Socket 7 Register
  11110 Selects Socket 7 TX Buffer
  11111 Selects Socket 7 RX Buffer

  Prima della trasmissione del byte, questi valori vengono shiftati << 3, portando a questi indirizzi finali sul byte SPI:

  Socket 0: Registers=0x08, TX=0x10, RX=0x18
  Socket 1: Registers=0x28, TX=0x30, RX=0x38
  Socket 2: Registers=0x48, TX=0x50, RX=0x58
  Socket 3: Registers=0x68, TX=0x70, RX=0x78
  Socket 4: Registers=0x88, TX=0x90, RX=0x98
  Socket 5: Registers=0xA8, TX=0xB0, RX=0xB8
  Socket 6: Registers=0xC8, TX=0xD0, RX=0xD8
  Socket 7: Registers=0xE8, TX=0xF0, RX=0xF8

  Pertanto definiamo le costanti gia' shiftate << 3 nella formula, cosi' risparmiamo di farlo fare al processore.
*/

// ---------------------------------------------------------
// Socket Status Register values (Sn_SR)
// ---------------------------------------------------------
#define SOCK_CLOSED         0x00
#define SOCK_INIT           0x13
#define SOCK_LISTEN         0x14
#define SOCK_SYNSENT        0x15
#define SOCK_SYNRECV        0x16
#define SOCK_ESTABLISHED    0x17
#define SOCK_FIN_WAIT       0x18
#define SOCK_CLOSING        0x1A
#define SOCK_TIME_WAIT      0x1B
#define SOCK_CLOSE_WAIT     0x1C
#define SOCK_LAST_ACK       0x1D
#define SOCK_UDP            0x22
#define SOCK_IPRAW          0x32
#define SOCK_MACRAW         0x42
#define SOCK_PPPOE          0x5F

// ---------------------------------------------------------
// Socket Command Register values (Sn_CR)
// ---------------------------------------------------------
#define CR_OPEN             0x01
#define CR_LISTEN           0x02
#define CR_DISCON           0x08
#define CR_CLOSE            0x10
#define CR_SEND             0x20
#define CR_RECV             0x40

// ---------------------------------------------------------
// Socket Mode Register values (Sn_MR)
// ---------------------------------------------------------
#define MR_TCP              0x01

// ---------------------------------------------------------
// PROXY state machine (real caller's IP detection)
// ---------------------------------------------------------
#define PROXYSTATE_IDLE     0
#define PROXYSTATE_PARSING  1
#define PROXYSTATE_PROXIED  2

const char PROXY_MAGIC[] = "PROXY TCP";

// ---------------------------------------------------------
//  LOCAL FUNCTIONS
// ---------------------------------------------------------
static uint8_t wizRead(uint16_t, uint8_t);
static uint16_t wizRead16(uint16_t, uint8_t);
static void wizBurstRead(uint16_t, uint8_t, uint8_t *, uint16_t);
static void wizWrite(uint16_t, uint8_t block, uint8_t);
static void wizWrite16(uint16_t, uint8_t block, uint16_t);
static void wizBurstWrite(uint16_t, uint8_t, const uint8_t *, uint16_t);
static uint8_t w5500_read_rx_byte(TelnetSession *, uint16_t);
static int8_t w5500_socket_listen(TelnetSession *);
static uint8_t wait_command_done(uint8_t);
static bool w5500_software_reset(void);
static uint8_t spiTransfer(uint8_t);
static bool telnet_rx_push(TelnetSession *, uint8_t);
static void telnet_negotiate_character_mode(TelnetSession *);
static void telnet_write_char(TelnetSession *, uint8_t);
static void telnet_tx_pop(TelnetSession *);
static void telnet_write_block(TelnetSession *, const uint8_t *, uint16_t);
static void w5500_disconnect(TelnetSession *);
static void systemResetSafe(void);
static void telnet_debug_regs(TelnetSession *);
static void telnet_struct_init(void);
static bool parse_ip_string(char*, uint8_t*);

// ---------------------------------------------------------
// VARIABLES
// ---------------------------------------------------------
NetConfig netcfg;
TelnetSession telnet_sessions[MAX_TELNET_SESSIONS];
bool eth_ok = false;

extern byte telnetSpecialCmds;
extern byte inTheMenu;
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

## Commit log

2026-05-09 firmware and software uploaded
    [XMODEM.CFG, XMODEM27.CFG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]
2026-05-17 bom added
    [A060126_BOM.csv]
2026-08-25 Updated bom
    [A060126_BOM.csv]
2026-09-28 IOS ethernet buffer bugfix
    [IOS-Z80-MBC2-V.ino, w5500.cpp]
